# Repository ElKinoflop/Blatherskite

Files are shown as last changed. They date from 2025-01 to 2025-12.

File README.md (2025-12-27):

# Blatherskite
Stacked acrylic/metal handwired 12.75u 40% keyboard with a push button and LED grid. There are two versions, v1 or v2. The obvious difference is the component cover but the whole case has slightly different dimensions to accomodate it.

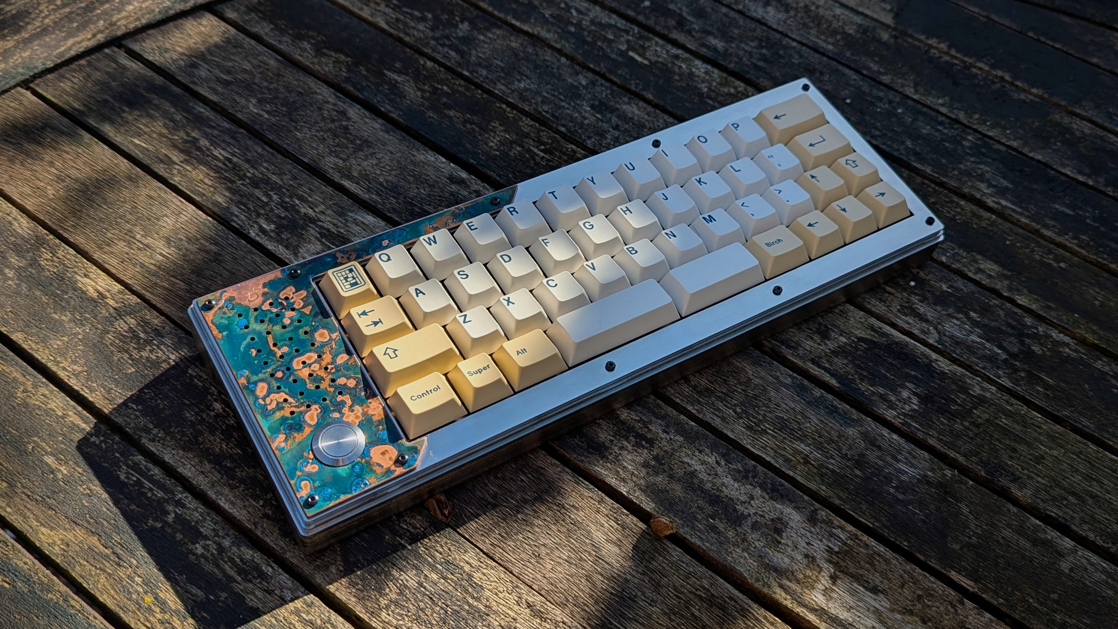
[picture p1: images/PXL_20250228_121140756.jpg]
Blatherskite v2 Photo


v1 - Untested
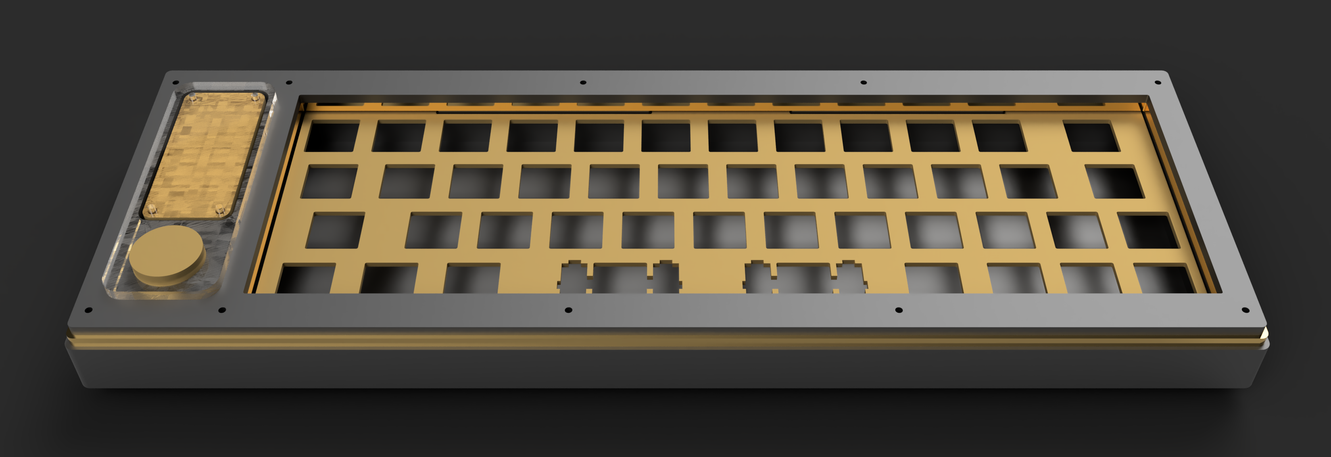
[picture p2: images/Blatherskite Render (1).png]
Blatherskite v1 Render


v2
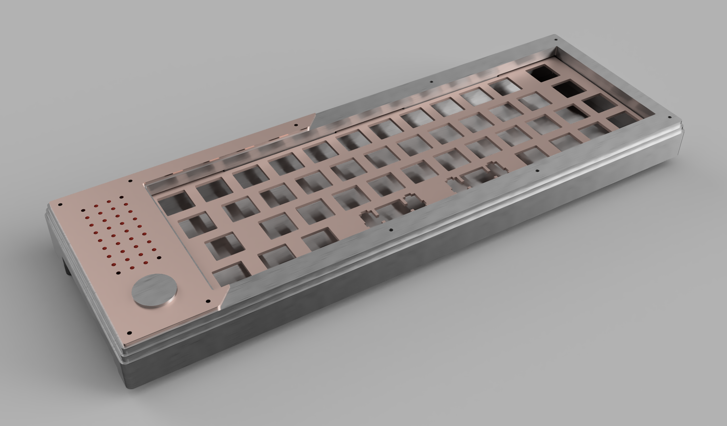
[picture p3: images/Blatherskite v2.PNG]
Blatherskite v2 Render


Feel free to do whatever you want with the files. If you have any questions just ask (Discord username elkinoflop) and if you make one then share a photo with me!

<h1>Inspiration</h1>
<ul>
  <li>Prkns' <a href="https://geekhack.org/index.php?topic=105358.0">Whimsy</a></li>
  <li>Aidan-OS' <a href="https://github.com/Aidan-OS/Mochi40" target="_blank">Mochi</a></li>
  <li>Footfingers' <a href="https://geekhack.org/index.php?topic=115295.0" target="_blank">Syrup</a></li>
  <li>Trashman's <a href="https://trashman.wiki/keyboards/minivan">Minivan</a></li>
  <li><a href="https://p3dstore.notion.site/P3Dstore-Open-Source-Project-List-6e85900337294e769fb7b8fa68d68f27">Jake/P3D's acrylic cases</a></li>
  <li><a href="https://smkeyboards.com/">SM Keyboards' acrylic cases</a></li>
</ul>

<h1>Layout</h1>
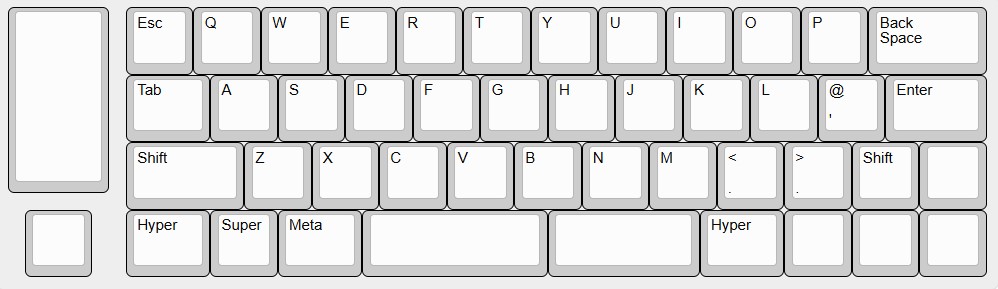
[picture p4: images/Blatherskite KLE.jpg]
Blatherskite Layout


<h1>KLE Raw Data</h1>

```json
[{"a":7,"w":1.5,"h":2.75},"",{"x":0.25,"a":4},"Esc","Q","W","E","R","T","Y","U","I","O","P",{"w":1.75},"Back<br>Space"],
[{"x":1.75,"w":1.25},"Tab","A","S","D","F","G","H","J","K","L","@\n'",{"w":1.5},"Enter"],
[{"x":1.75,"w":1.75},"Shift","Z","X","C","V","B","N","M","<\n.",">\n.","Shift",{"a":7},""],
[{"x":0.25},"",{"x":0.5,"a":4,"w":1.25},"Hyper","Super",{"w":1.25},"Meta",{"a":7,"w":2.75},"",{"w":2.25},"",{"a":4,"w":1.25},"Hyper",{"a":7},"","",""]
```

<h1>Case Manufacturing</h1>
<ul>
  <li><a href="https://github.com/ElKinoflop/Blatherskite/tree/main/case%20files" target="_blank">Case files</a></li>
  <li>Designed to be cut from 3mm acrylic. There are images of one I got made from stacked steel/copper however really the bolt/standoff hole diameters need increasing by 0.2-0.5mm for metal (at least with LaserBoost).</li>
  <li>Note that acrylic sheets can vary in thickness even if they are listed as 3mm. I have found that Perspex® typically measures at 3-3.1mm whereas Xintao (which most Chinese suppliers seem to use) typically comes in at 2.6-2.7mm. This doesn't matter too much except for your switches will be much more visible with thinner sheets and it will be a tighter squeeze in the case for the wiring.</li>
  <li>Don't force the standoffs through if you find some of the standoffs too tight. Use a small round file if you need to slightly widen any holes. The small round file from Draper 'Soft Grip Needle File Set, 140mm (6 Piece) (83982)' is the perfect size. You shouldn't need to do this but there can be some manufacturing variance.</li>
</ul>

<h1>Bill of Materials</h1>
<ul>
  <li>One of each (either v1 or v2) <a href="https://github.com/ElKinoflop/Blatherskite/tree/main/case%20files" target="_blank">case layer</a> cut from 3mm acrylic. You need two of the feet (unless you want a lower angle) and two of 'Blatherskite v2 5-6 - Mid Middle-Upper.dxf' for v2. For v2 there are two versions of layer 1 (top). If you have layer 0 (accent) cut from 1.5mm material you should use 'Blatherskite Alt 1 - Top.dxf'. If you have layer 0 (accent) cut from 3mm material you should use 'Blatherskite v2 1 - Top - Open Button Cutout.dxf' otherwise the stack will be too thick to screw the button nut on.</li>
  <li>Plate DXF file cut from 1.5mm metal/carbon. Flexier/plastic plates aren't recommened as without a PCB you can bottom out the switches on the case and risk the switches popping out of the plate</li>
  <li><a href="https://mechboards.co.uk/products/pro-micro-5v?_pos=2&_sid=c64ff0323&_ss=r" target="_blank">Pro Micro footprint RP2040 controller</a></li>
  <li>Sockets and pins to socket the controller</li>
  <li>M2 Standoffs with a outside diameter of 3mm. <a href="https://amzn.eu/d/8H1HG6Y" target="_blank">Amazon Standoffs</a></li></li>
  <li>M2 Hex socket button head bolts. Various lengths between 4-12mm. <a href="https://www.aliexpress.com/item/32969042589.html" target="_blank">AliExpress bolts</a></li>
  <li><a href="https://www.adafruit.com/product/2884" target="_blank">FeatherWing Proto board</a></li>
  <li>Adhesive gasket material. 4mm width. I used 2mm thick gaskets but slightly thinner would be better.</li>
  <li>Wire! Solid core 22 AWG suggested</li>
  <li>45x MX Switches</li>
  <li>45x 1N4148 Diodes (plus any extras if you have buttons/encoders in the middle)</li>
  <li>4x small adhesive feet</li>
  <li><a href="https://www.adafruit.com/product/2945" target="_blank">Adafruit NeoPixel FeatherWing</a></li>
  <li><a href="https://www.aliexpress.com/item/1005004920346156.html" target="_blank">16mm momentary push button</a></li>
</ul>

<h1>Firmware</h1>
I used <a href="https://github.com/JanLunge/pog" target="_blank">POG</a> to create the firmware, it makes things super easy without any coding knowledge required

<h1>Controller Assembly</h1>
The controller, FeatherWing Proto and NeoPixel FeatherWing need assembling as pictured. I would advise socketing the controller and the ground and control pins that go to the NeoPixel FeatherWing. You can't socket the 5v connection as the pins don't line up so I have connected those with a short length of wire. The trace circled red needs cutting so the controller pins aren't shorted . The pads circled green need bridging with solder so that pin can be used to control the LEDs.
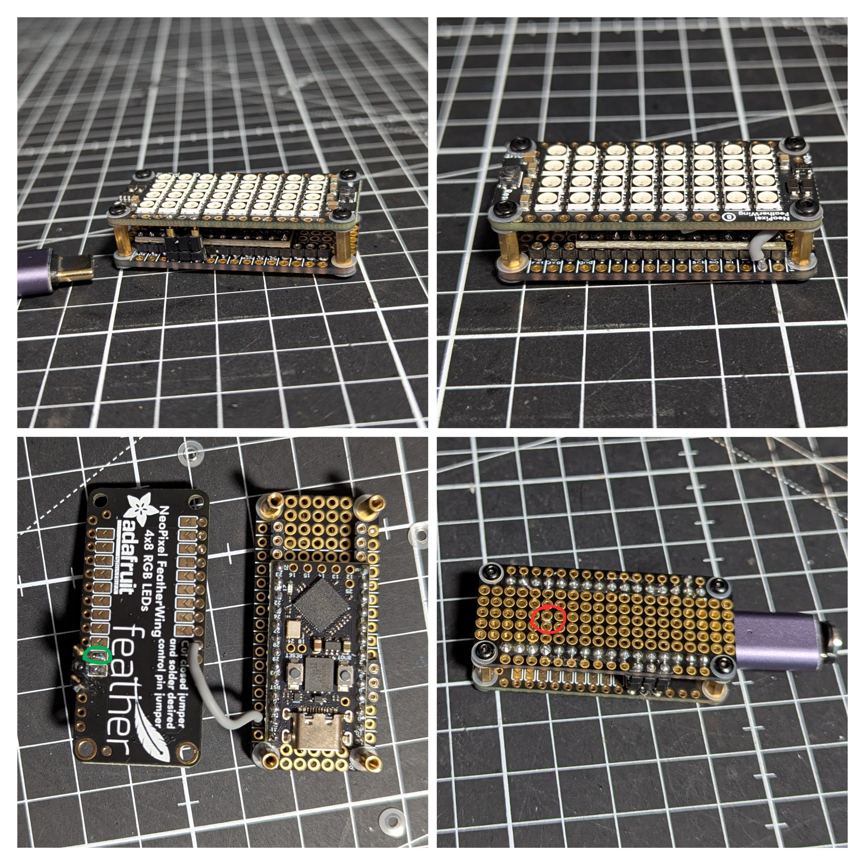
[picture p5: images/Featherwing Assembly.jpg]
Controller Assembly


LEDs

<h1>Disclaimer</h1>
V1 is currently untested. With all versions you are ordering at your own risk and there are no guarantees that you end up with a functional item. If you do notice any mistakes please contact me (Discord username elkinoflop) so I can fix them.

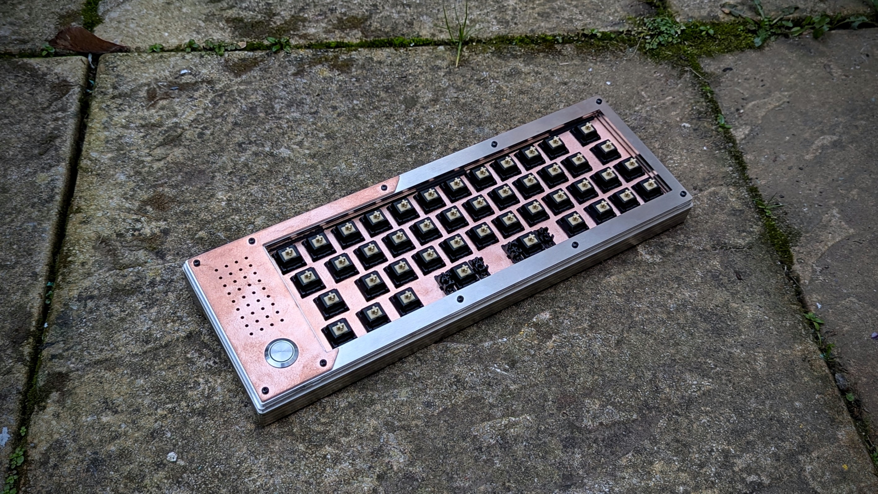
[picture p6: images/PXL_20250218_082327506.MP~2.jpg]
Blatherskite Photo


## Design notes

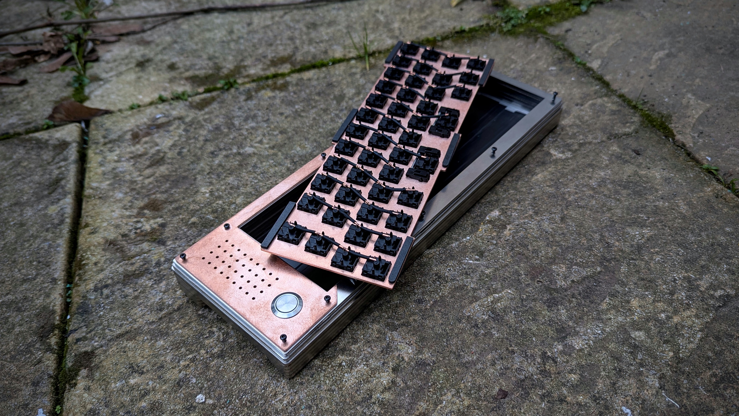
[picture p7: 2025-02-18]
images/PXL_20250218_081947447.MP~2.jpg

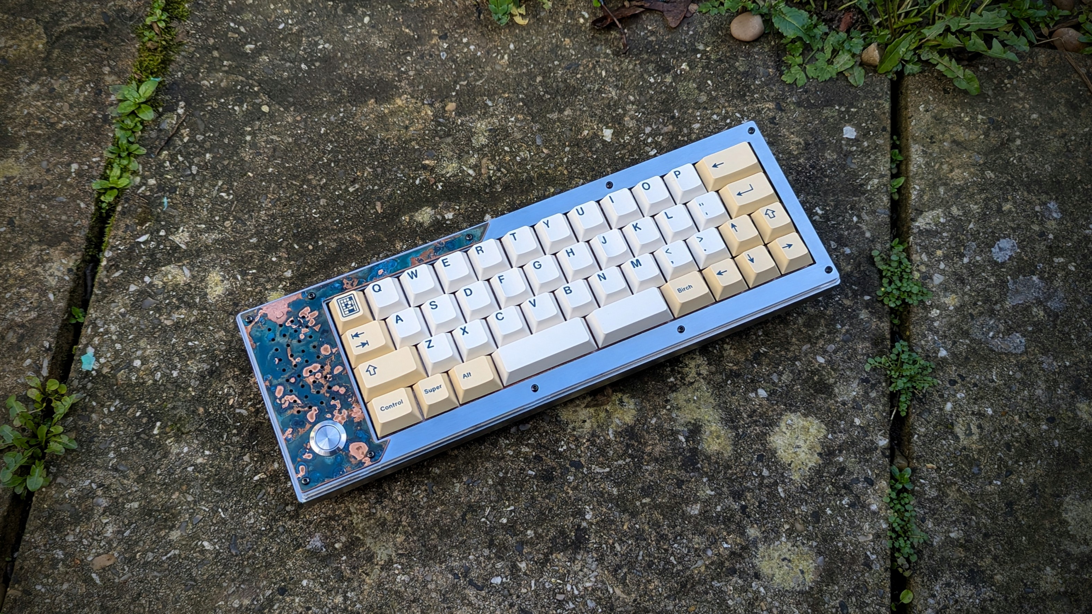
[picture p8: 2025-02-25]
images/PXL_20250225_100557531~2.jpg

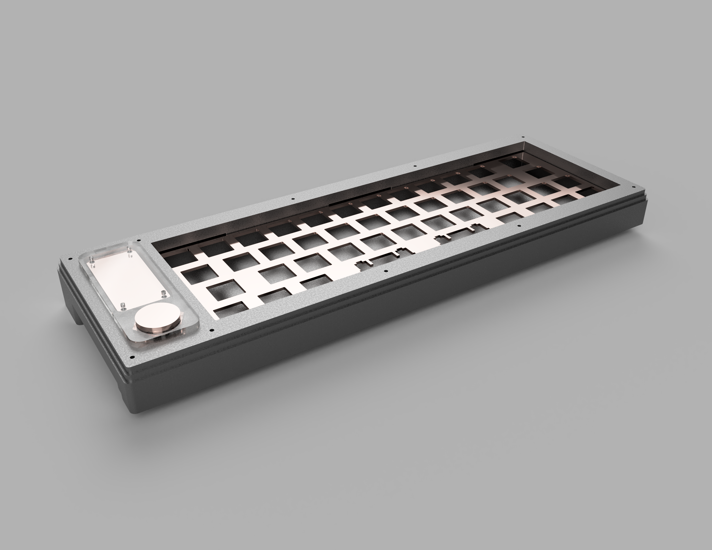
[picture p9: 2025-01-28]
images/Blatherskite Render (2).png

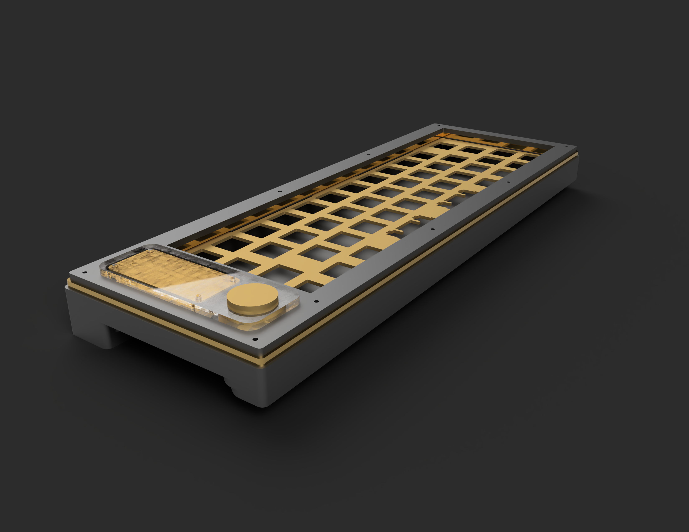
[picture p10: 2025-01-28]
images/Blatherskite Render (3).png

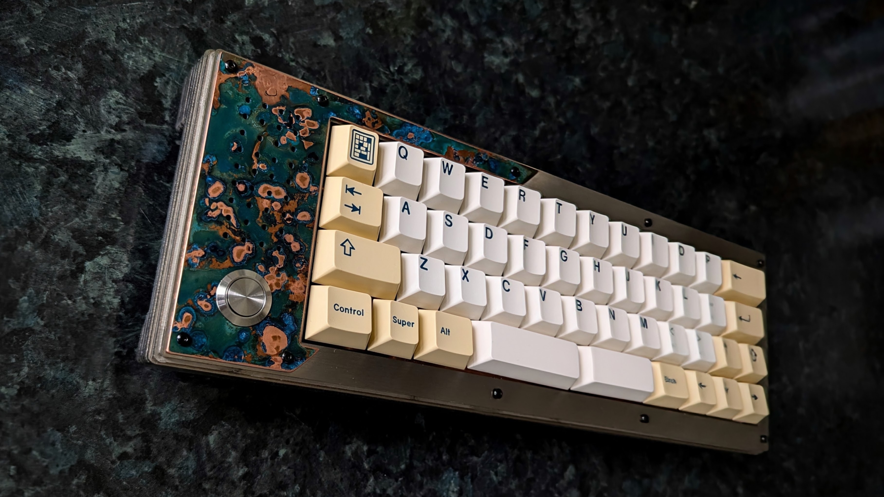
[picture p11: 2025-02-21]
images/PXL_20250221_104916242.MP-EDIT~2.jpg

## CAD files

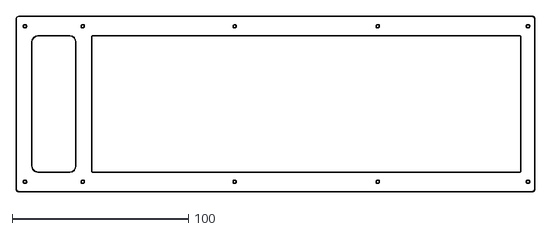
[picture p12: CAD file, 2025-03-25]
case files/Blatherskite v2 1 - Top - Open Button Cutout.dxf
294.8 x 99.5

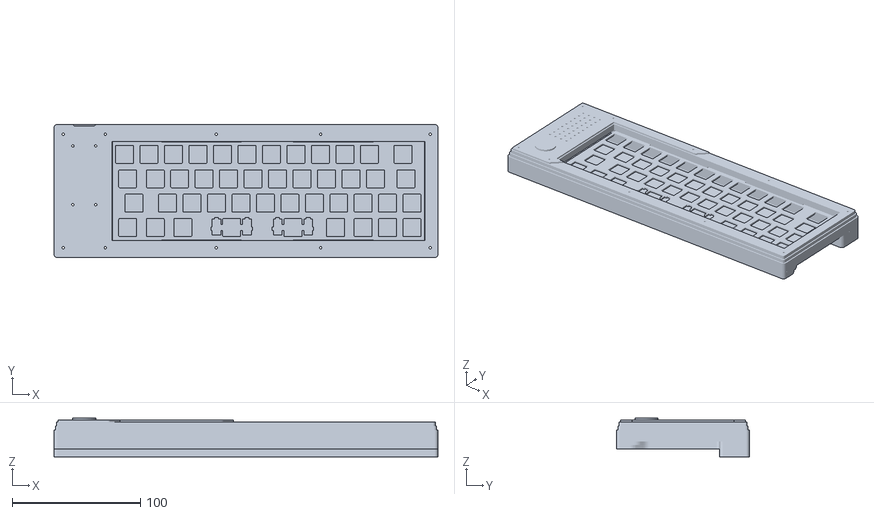
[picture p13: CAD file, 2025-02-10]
images/Blatherskite Alt Remade v4.stl
299.0 x 103.7 x 30.0

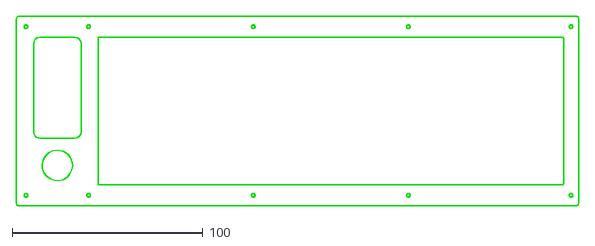
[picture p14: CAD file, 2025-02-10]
case files/Blatherskite v2 1 - Top.dxf
294.8 x 99.5

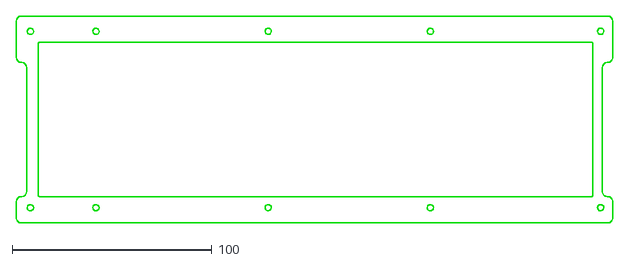
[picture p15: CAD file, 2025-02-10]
case files/Blatherskite v2 7 - Mid Lower PR.dxf
299.0 x 103.7

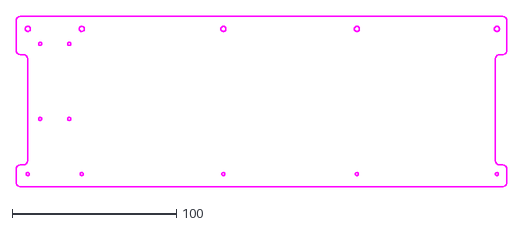
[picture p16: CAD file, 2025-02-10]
case files/Blatherskite v2 8 - Bottom PR.dxf
299.0 x 103.7

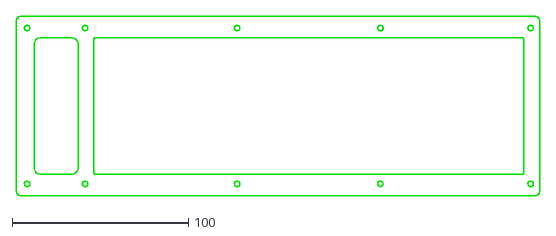
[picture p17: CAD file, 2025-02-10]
case files/Blatherskite v2 2 - Accent.dxf
296.9 x 101.6

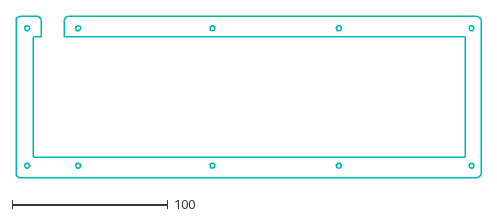
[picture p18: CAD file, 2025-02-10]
case files/Blatherskite v2 5-6 - Mid Middle-Upper.dxf
299.0 x 103.7

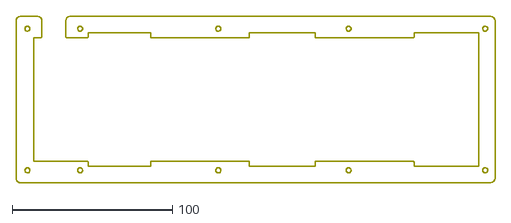
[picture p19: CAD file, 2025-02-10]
case files/Blatherskite v2 4 - Plate Layer.dxf
299.0 x 103.7

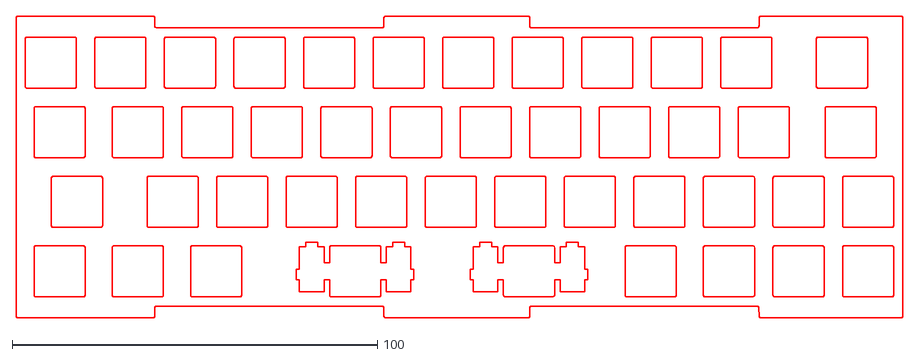
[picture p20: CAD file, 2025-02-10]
case files/Blatherskite v2 3 - Plate.dxf
242.9 x 82.6

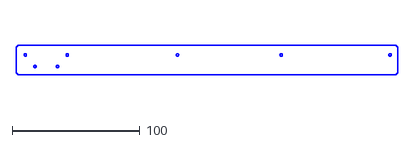
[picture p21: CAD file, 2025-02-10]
case files/Blatherskite v2 9 - Feet.dxf
299.0 x 23.3

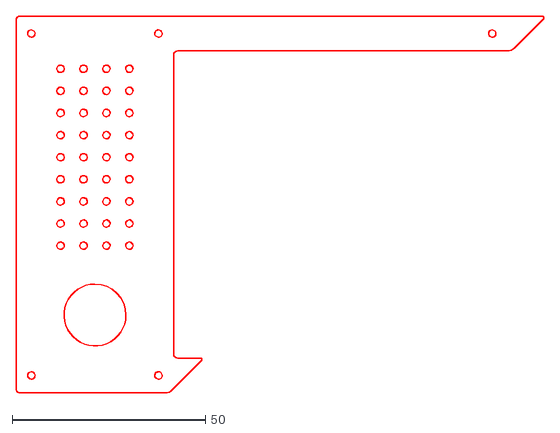
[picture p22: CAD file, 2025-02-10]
case files/Blatherskite v2 0 - Component Cover Holes Slant Extended.dxf
136.5 x 97.4

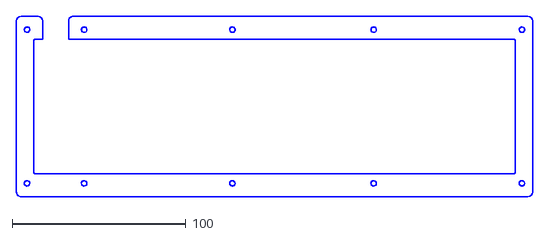
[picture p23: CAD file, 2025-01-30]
case files/Blatherskite 5 - Mid Upper.dxf
296.9 x 103.7

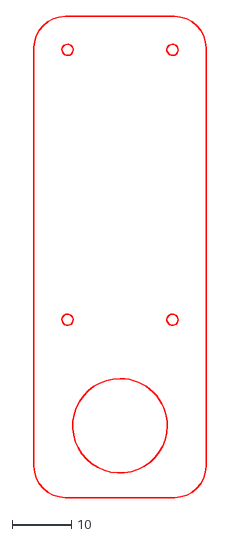
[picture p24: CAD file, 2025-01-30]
case files/Blatherskite 0 - Component Cover.dxf
29.2 x 81.5

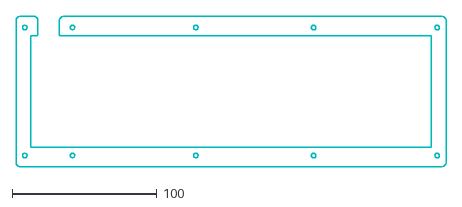
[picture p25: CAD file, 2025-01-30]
case files/Blatherskite 6 - Mid Middle.dxf
296.9 x 103.7

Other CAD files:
case files/Blatherskite 7 - Mid Lower PR.dxf
case files/Blatherskite 8 - Bottom PR.dxf
case files/Blatherskite 4 - Plate Layer.dxf
case files/Blatherskite 1 - Top.dxf
case files/Blatherskite 2 - Accent.dxf
case files/Blatherskite 3 - Plate.dxf
case files/Blatherskite 9 - Feet.dxf

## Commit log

2025-02-10 Rename Blatherskite Alt 0 - Component Cover Holes Slant Extended.dxf to Blatherskite v2 0 - Component Cover Holes Slant Extended.dxf
    [Blatherskite v2 0 - Component Cover Holes Slant Extended.dxf]
2025-02-10 Rename Blatherskite Alt 1 - Top.dxf to Blatherskite v2 - Top.dxf
    [Blatherskite v2 - Top.dxf]
2025-02-10 Rename Blatherskite v2 - Top.dxf to Blatherskite v2 - 1 Top.dxf
    [Blatherskite v2 - 1 Top.dxf]
2025-02-10 Rename Blatherskite v2 - 1 Top.dxf to Blatherskite v2 1 - Top.dxf
    [Blatherskite v2 1 - Top.dxf]
2025-02-10 Rename Blatherskite Alt 2 - Accent.dxf to Blatherskite v2 2 - Accent.dxf
    [Blatherskite v2 2 - Accent.dxf]
2025-02-10 Rename Blatherskite Alt 3 - Plate.dxf to Blatherskite v2 3 - Plate.dxf
    [Blatherskite v2 3 - Plate.dxf]
2025-02-10 Rename Blatherskite Alt 4 - Plate Layer.dxf to Blatherskite v2 4 - Plate Layer.dxf
    [Blatherskite v2 4 - Plate Layer.dxf]
2025-02-10 Rename Blatherskite Alt 5-6 - Mid Middle-Upper.dxf to Blatherskite v2 5-6 - Mid Middle-Upper.dxf
    [Blatherskite v2 5-6 - Mid Middle-Upper.dxf]
2025-02-10 Rename Blatherskite Alt 7 - Mid Lower PR.dxf to Blatherskite v2 7 - Mid Lower PR.dxf
    [Blatherskite v2 7 - Mid Lower PR.dxf]
2025-02-10 Rename Blatherskite Alt 8 - Bottom PR.dxf to Blatherskite v2 8 - Bottom PR.dxf
    [Blatherskite v2 8 - Bottom PR.dxf]
2025-02-10 Rename Blatherskite Alt 9 - Feet.dxf to Blatherskite v2 9 - Feet.dxf
    [Blatherskite v2 9 - Feet.dxf]
2025-03-25 Update README.md
    Added an alternative version of v2 layer 1 to accommodate cutting the accent from either 1.5mm or 3mm material.
